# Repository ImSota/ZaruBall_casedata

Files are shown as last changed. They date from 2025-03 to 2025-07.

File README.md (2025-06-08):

# ZaruBall用3Dプリントデータ
ZaruBallとMackのケース、トラックボールケース、ロータリーエンコーダー用ノブのstlファイルを公開しています。<br>
mainブランチのデータはZaruBall v3以降のケースデータです。
v3より前のケースデータはversion1ブランチに保管してあります。

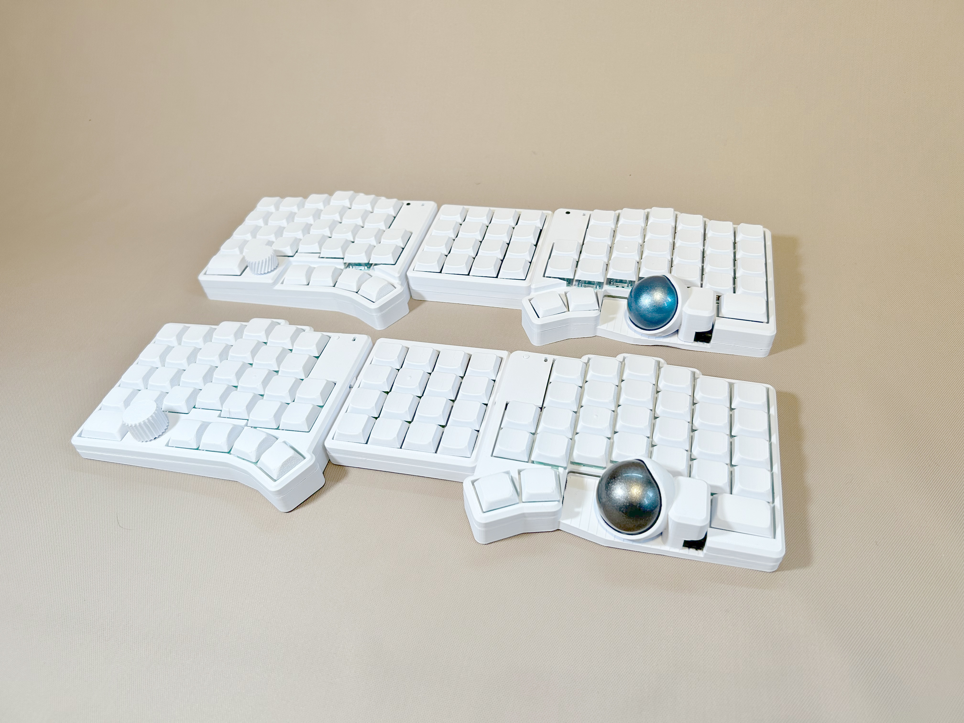
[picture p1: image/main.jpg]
main image


## ケースデータ
データ画保管先は[こちら](/case)<br>

ボトムケースはMack対応版とMack非対応版の2種類があります。
トップケースはロープロファイル版とMX版の2種類があります。
ファイル名の末尾で判別してください。
| 末尾の文字列 | 種類 |
| ---- | ---- |
| Mack | Mack対応版 |
| noMack | Mack非対応版 |
| LP | ロープロファイル版 |
| NP | MX版 |
<br>

3Dプリントパーツの他にも用意するパーツがあります。
| 用意するパーツ | 点数 | 寸法 |
| ---- | ---- | ---- |
| ネオジム磁石(ケース固定用) | ZaruBall:32個 Mack:8個 トラックボールケース:3個 | 直径2mm, 高さ2mmの円筒形 |
| ネオジム磁石(ZaruBall-Mack接続用) | 8個 | 直径6mm, 高さ2.5mmの円筒形 |
| セラミックボール | 3個 |  直径2mm |
| ゴム足 | ZaruBall:8個 Mack:4個 | 直径10mm |

## 組み立て方法

右手側のケース組み立て手順をご説明します。左手側、Mackもほぼ同様の手順で組み立てられます。
1. ケース固定用マグネットをトップケース、ボトムケース、トラックボールケースに圧入します。マグネットが入らない場合は2mmのドリルやマイナスドライバで穴を拡張します。緩く、マグネットが抜けてしまう場合は接着剤を穴に少量入れて固定してください。<br>
ボトムケースのトラックボール固定用マグネットは25mmボールと35mmボールで配置が異なります。トラックボールケースをボトムケースに当てはめてみて適切なマグネットの位置を探してください。
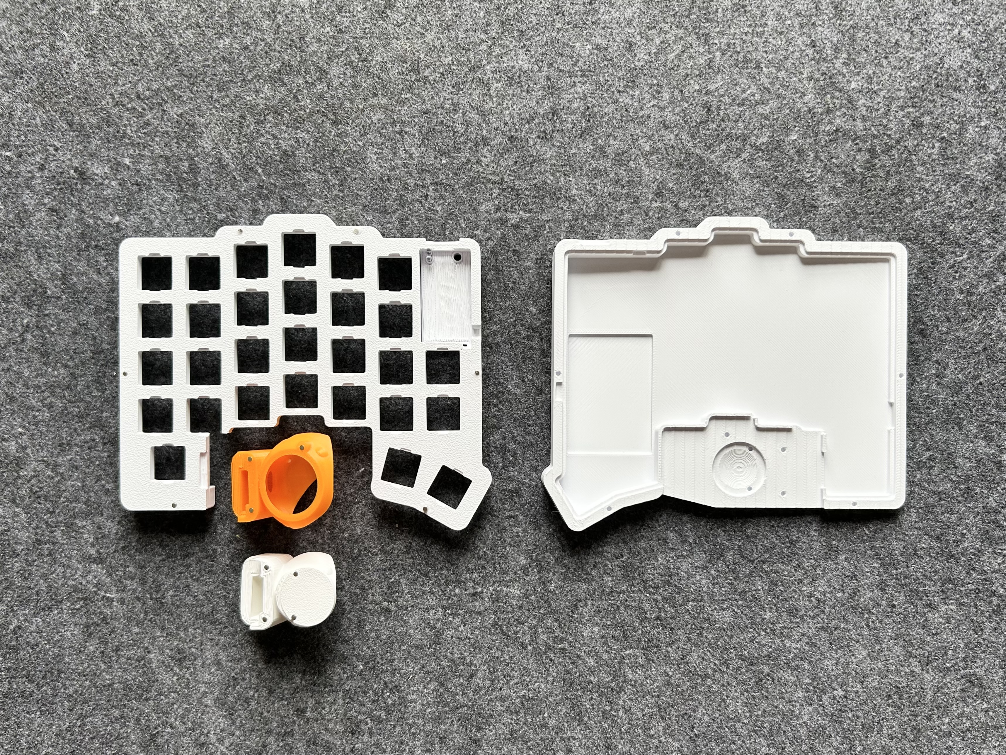
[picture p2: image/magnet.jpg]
insert magnet
    
2. セラミックボール3つをトラックボールケースに圧入します。固いものを押し当てることで簡単に圧入することができます。
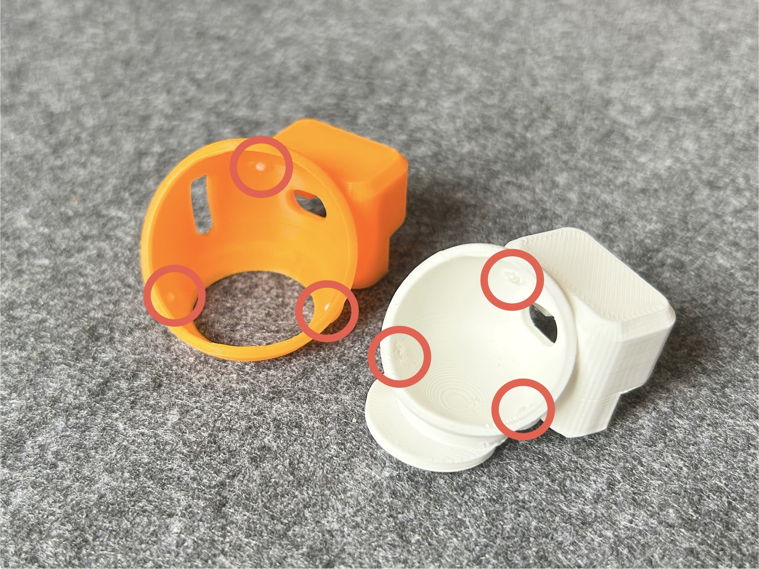
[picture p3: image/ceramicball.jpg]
insert_ceramic ball
    
3. トップケースにリセットスイッチと電源スイッチカバーを配置します。
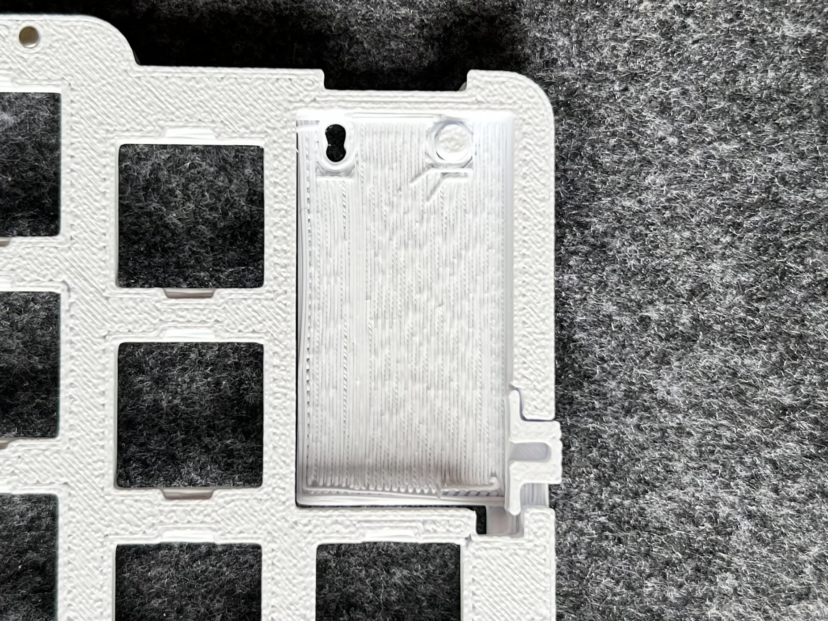
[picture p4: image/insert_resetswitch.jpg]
insert reset switch and power switch cover
    
4. PCBをトップケースにはめ込む。この時USB端子と電源スイッチを先にケースに入れるようにします。また、リセットスイッチが抜けないよう逆さにしたまま作業します。
    insert PCB
5. 四隅にスイッチをはめて、PCBとトップケースを固定します
    insert switches
6. ゴム足をボトムケースに貼付します。ゴム足固定用のくぼみがあるのでそこに合わせて貼り付けてください。
    putting rubberfeet
7. ボトムケースにMack接続用のΦ6mmマグネットを接着します。接続先のマグネットと吸着する向きにしてください。
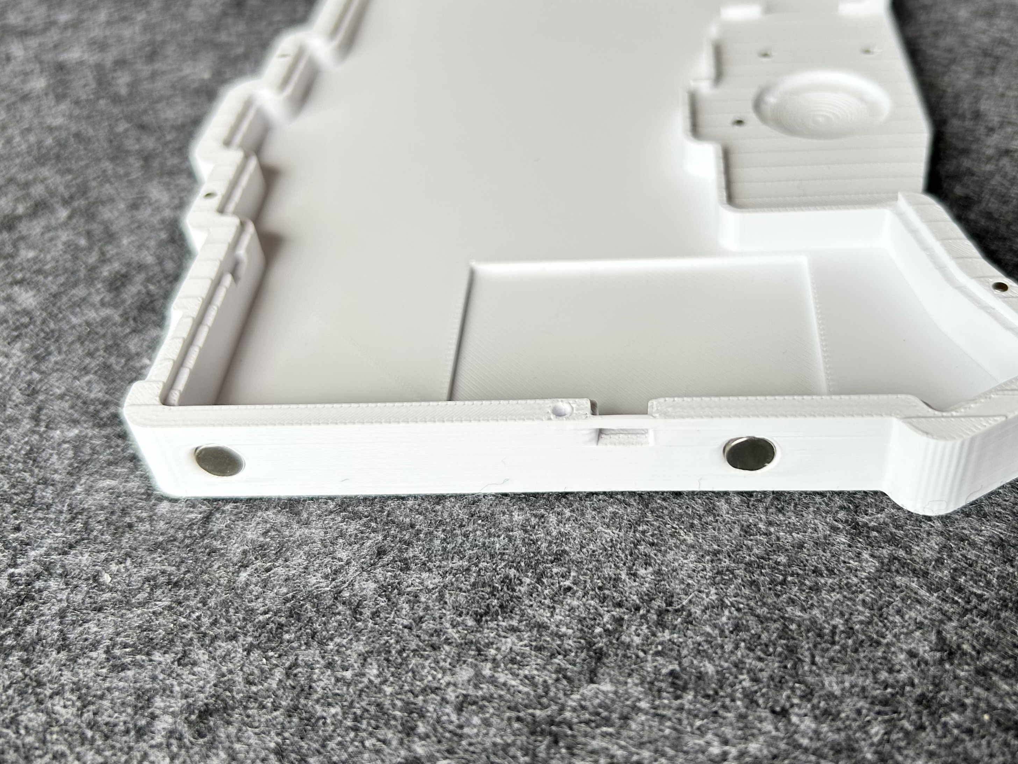
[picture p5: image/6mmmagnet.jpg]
6mm magnet
    
7. バッテリをボトムケースにマスキングテープ等で固定します。くぼみがあるのでそこにバッテリーを配置してください。
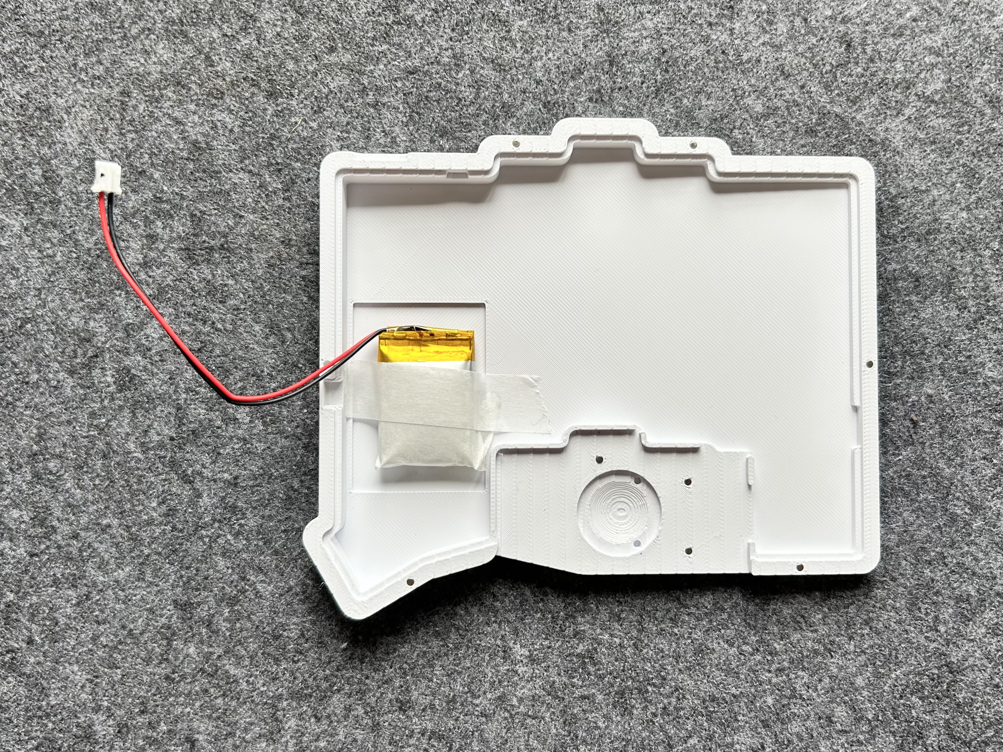
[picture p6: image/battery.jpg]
pinning battery
    
8. バッテリコネクタを接続し、ボトムケースとトップケースをマグネットで固定します。
9. すべてのスイッチとキーキャップ、トラックボール、ノブを取り付けます。
10. トラックボール基板のマグネットコネクタをPCBと接続し、トラックボール基板の上からトラックボールケースを被せます。
    trackball connect
11. マイコンのインジケータLEDの確認穴に2mmのアクリル丸棒を差し込むことで光が拡散し見やすくなります。
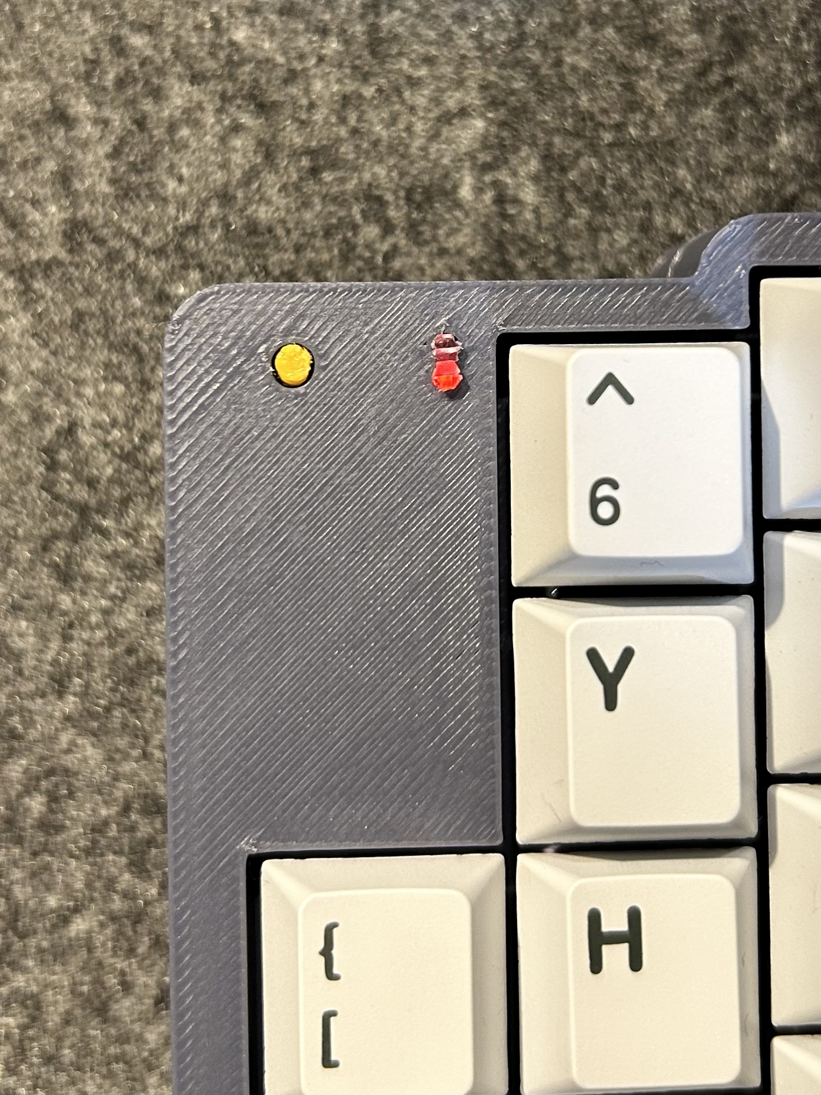
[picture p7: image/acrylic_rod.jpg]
insert acrylic rod


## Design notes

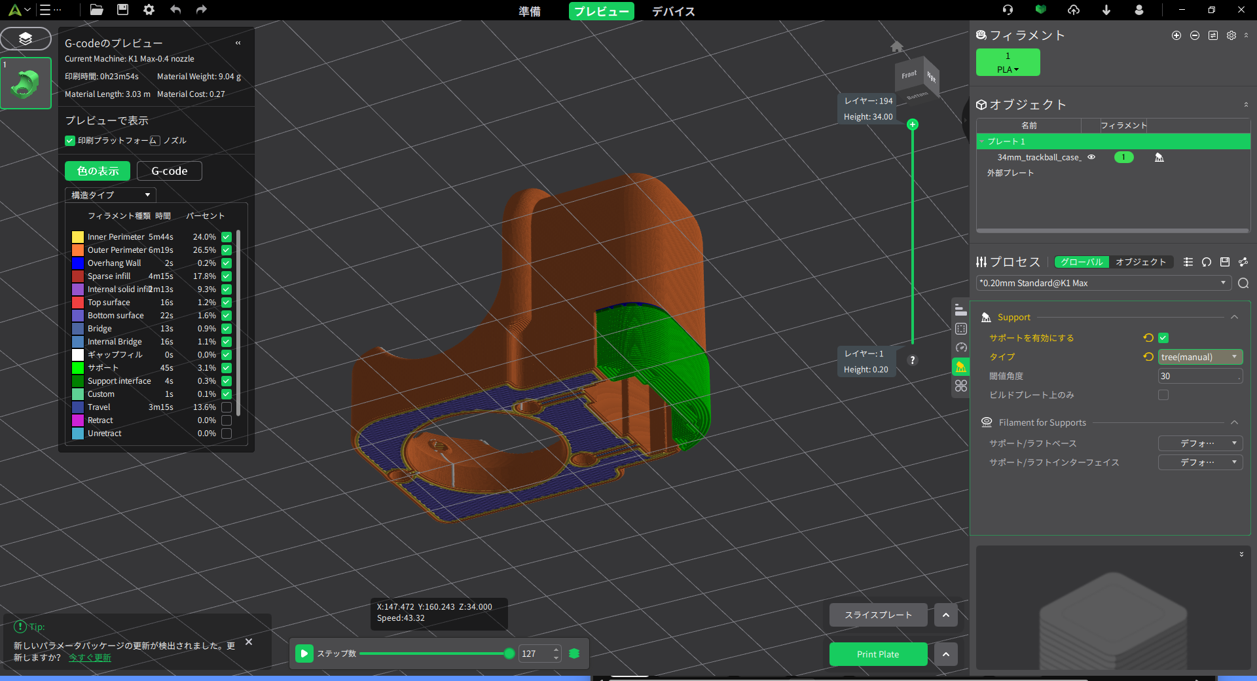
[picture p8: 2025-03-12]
image/image.png

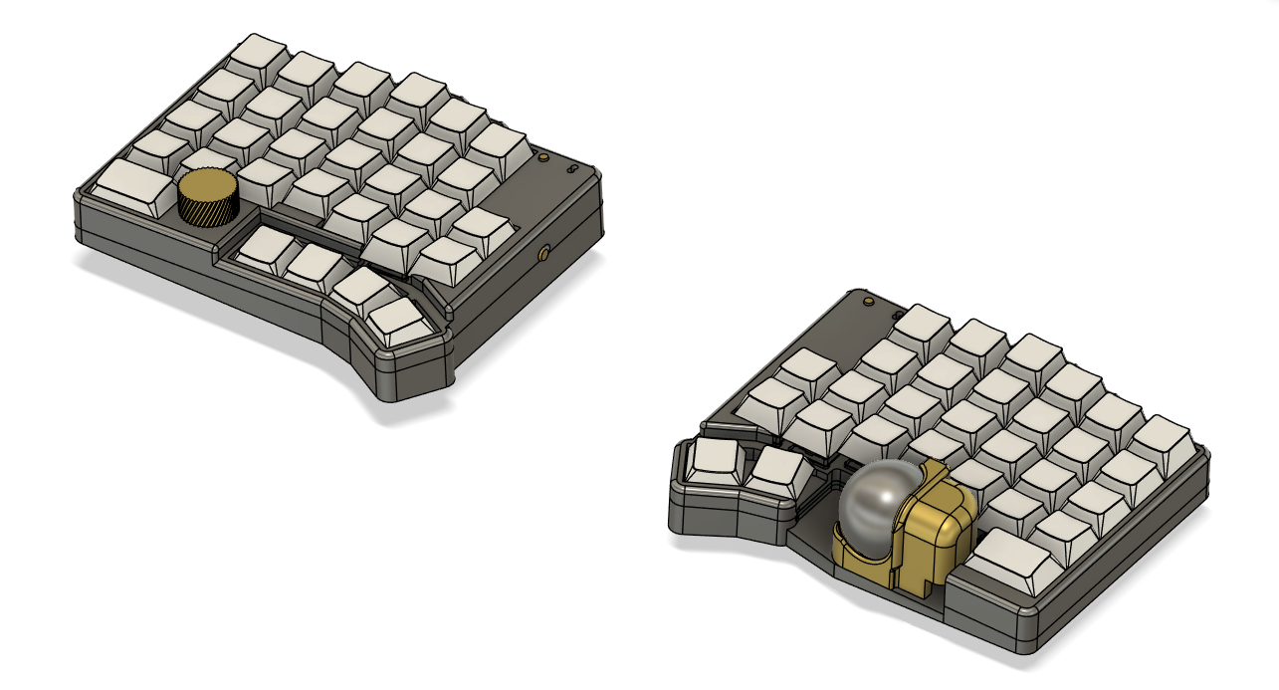
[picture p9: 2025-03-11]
image/2Pcase.png

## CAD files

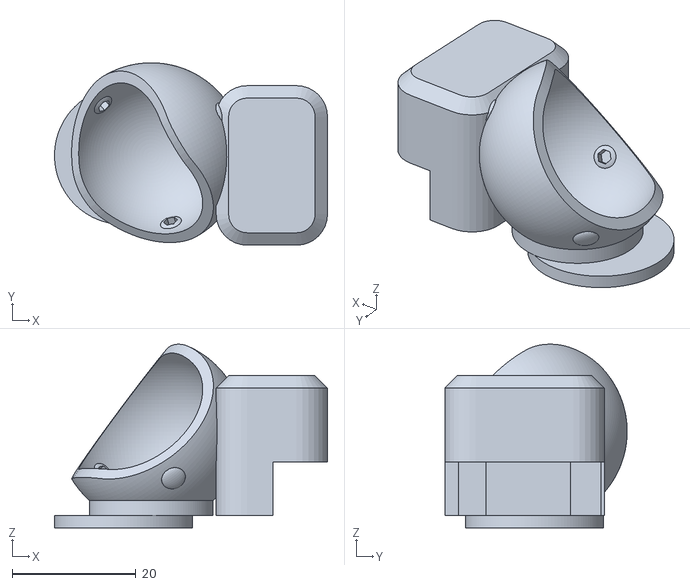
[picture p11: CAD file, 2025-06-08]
case/25mm_trackball.stl
44.1 x 29.5 x 29.7

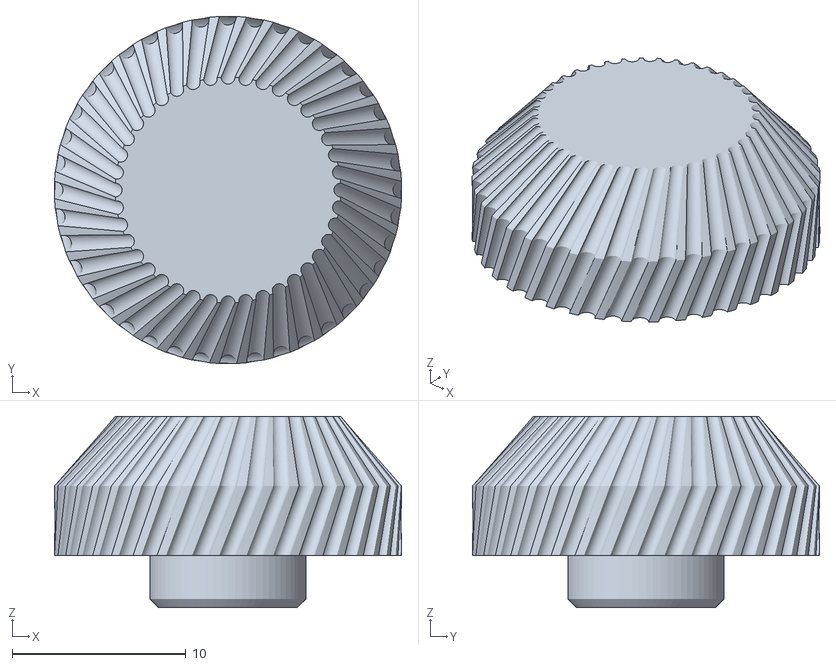
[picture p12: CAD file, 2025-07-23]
case/Knob/knob_LP.stl
20.0 x 20.0 x 11.0

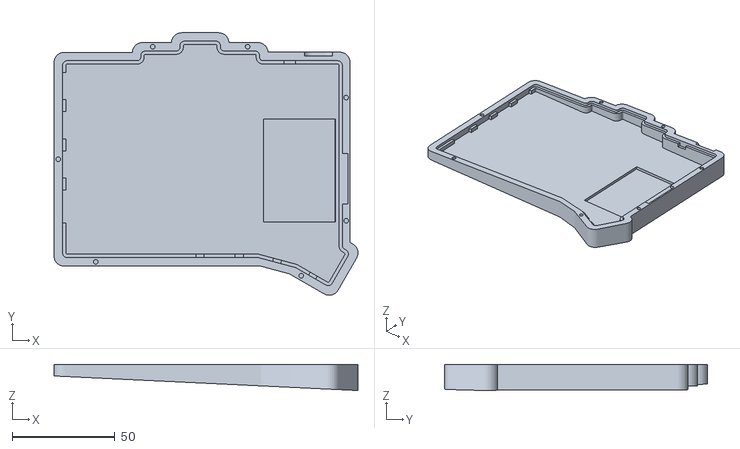
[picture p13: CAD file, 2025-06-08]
case/Left/bottom_noMack.stl
148.0 x 127.8 x 12.7

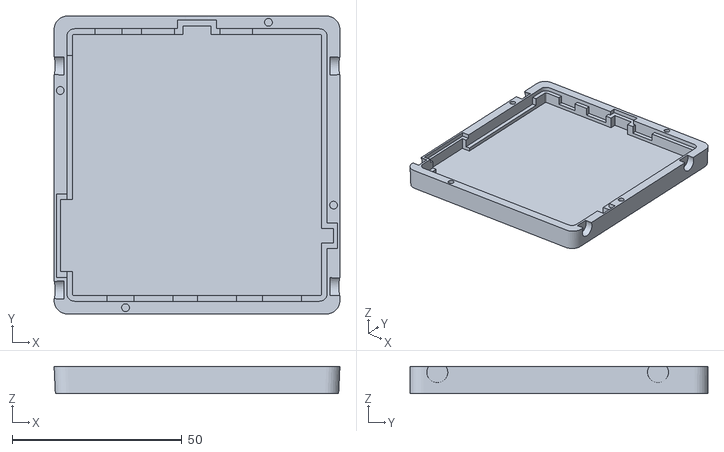
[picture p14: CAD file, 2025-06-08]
case/Mack/bottom.stl
84.2 x 87.8 x 8.00

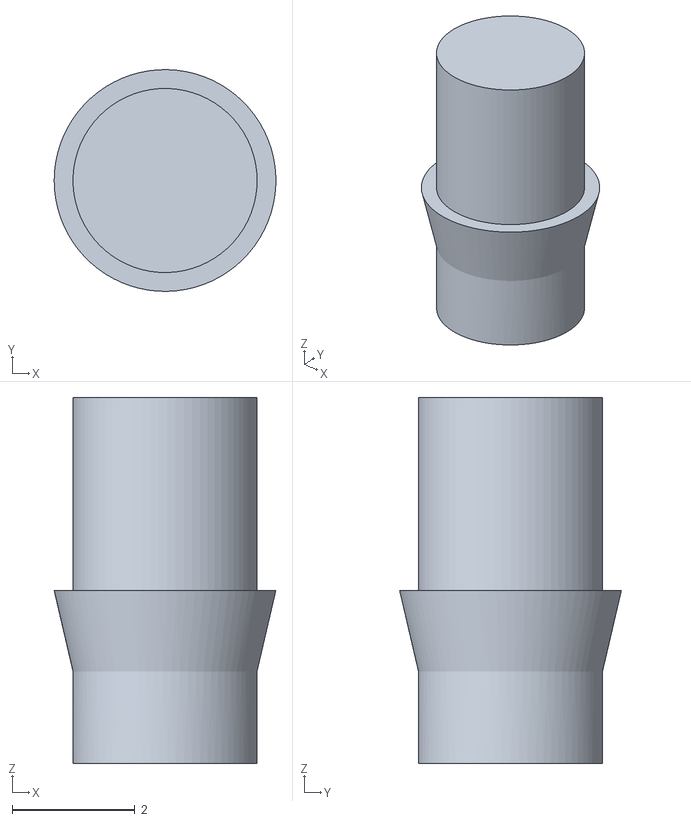
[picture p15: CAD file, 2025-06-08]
case/Reset_switch/reset_LP.stl
3.61 x 3.61 x 5.96

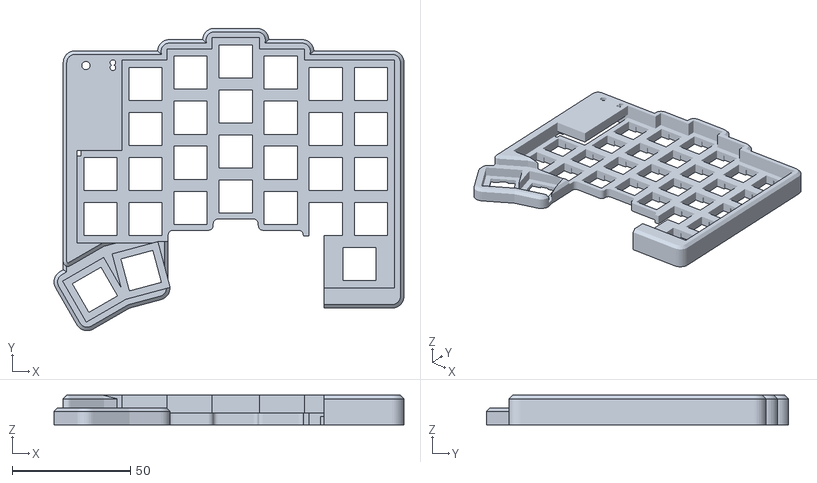
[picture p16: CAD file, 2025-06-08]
case/Right/top_NP.stl
148.0 x 127.9 x 12.5

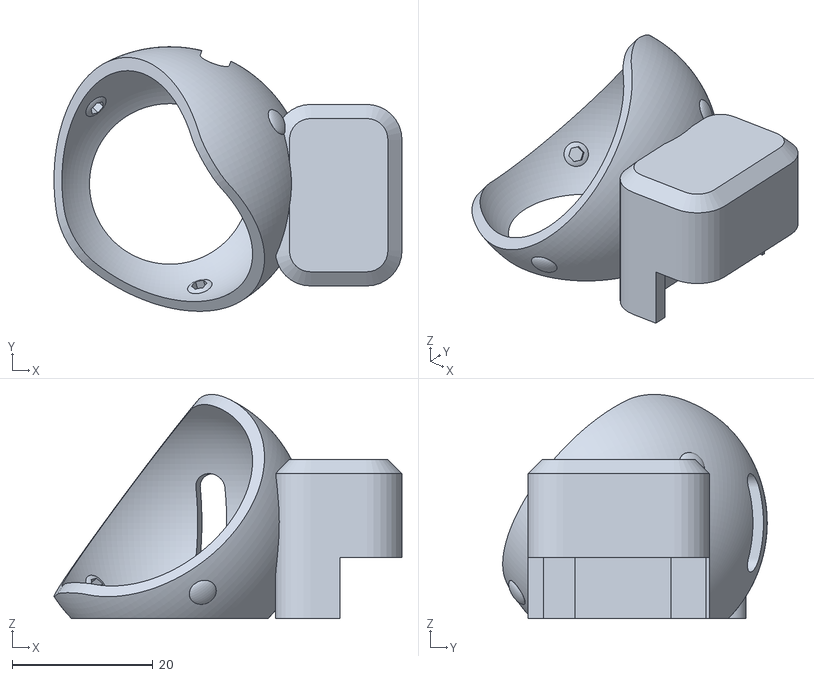
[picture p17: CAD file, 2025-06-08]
case/35mm_trackball.stl
49.5 x 37.6 x 31.9

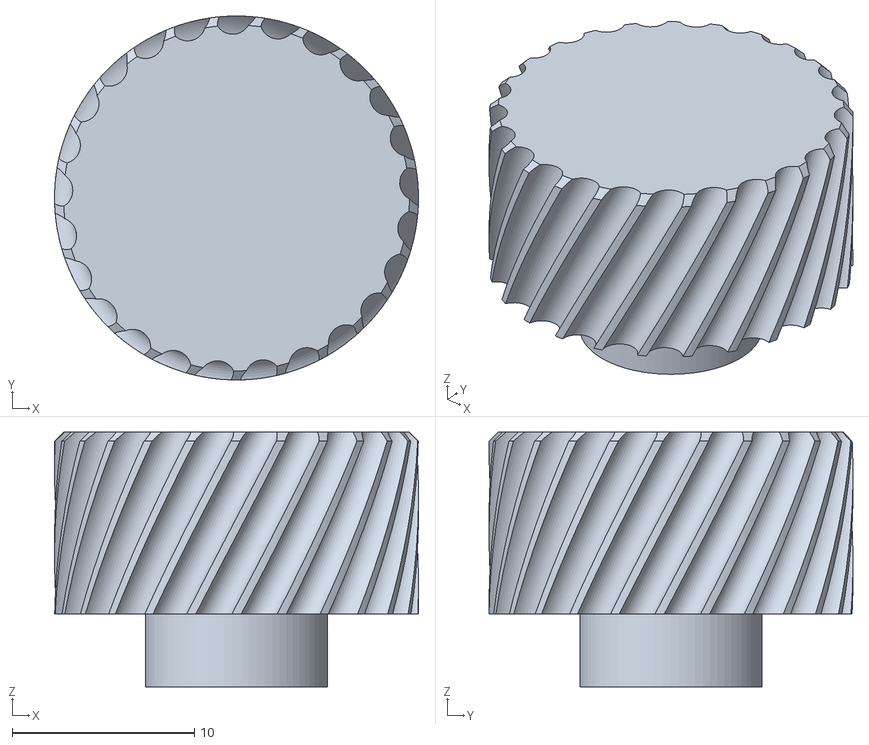
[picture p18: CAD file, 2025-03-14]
case/Knob/knob_NP.stl
20.0 x 20.0 x 14.0

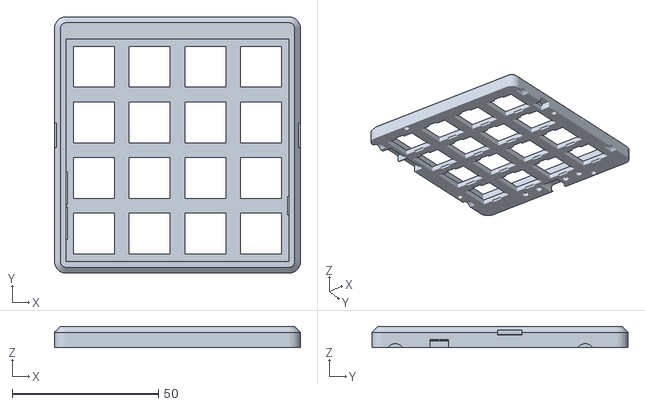
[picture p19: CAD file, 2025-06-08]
case/Mack/top_LP.stl
84.2 x 87.8 x 7.25

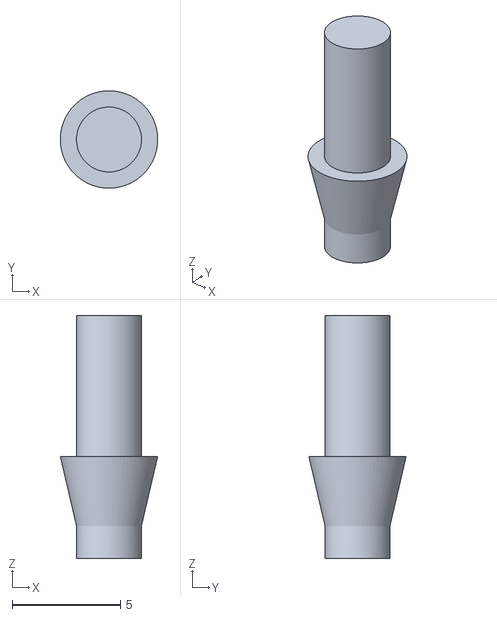
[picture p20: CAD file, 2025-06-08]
case/Reset_switch/reset_NP.stl
4.50 x 4.50 x 11.2

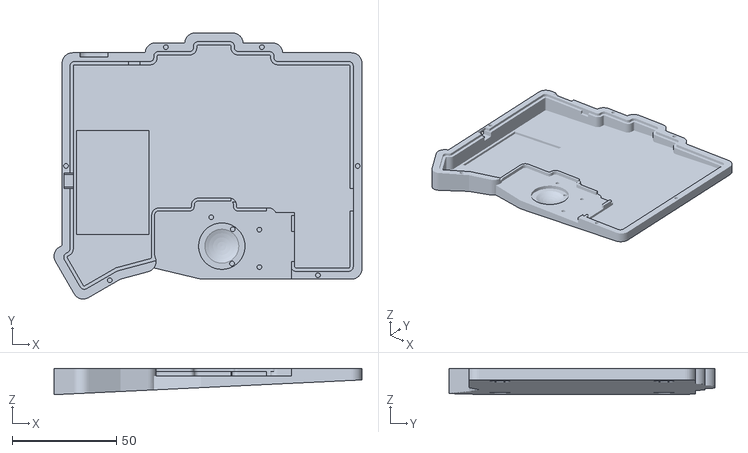
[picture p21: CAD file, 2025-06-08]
case/Right/bottom_Mack.stl
148.0 x 127.9 x 12.7

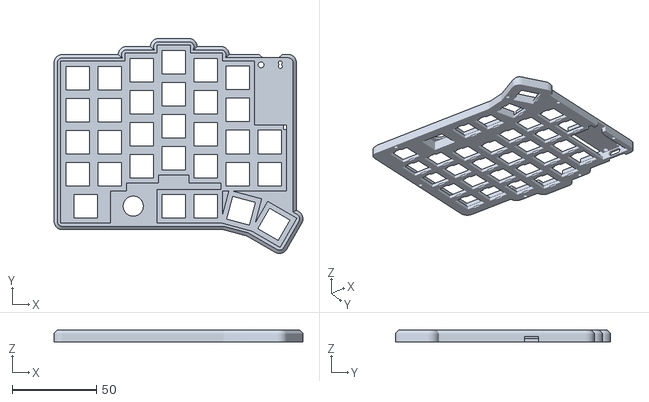
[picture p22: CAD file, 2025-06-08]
case/Left/top_LP.stl
148.0 x 127.8 x 7.20

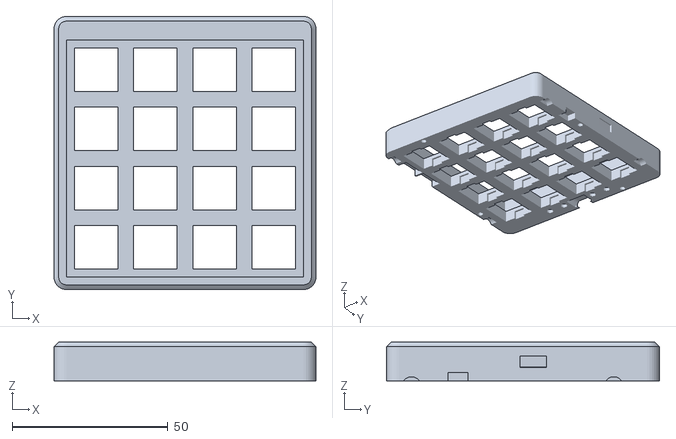
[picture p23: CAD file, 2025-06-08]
case/Mack/top_NP.stl
84.2 x 87.8 x 12.5

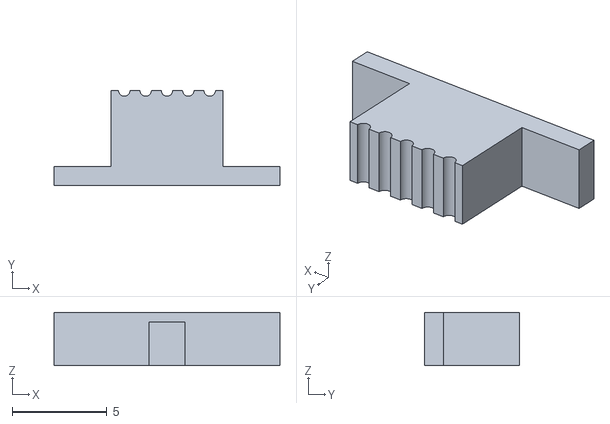
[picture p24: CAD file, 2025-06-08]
case/power_switch.stl
11.9 x 5.00 x 2.80

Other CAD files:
case/Left/bottom_Mack.stl
case/Right/bottom_noMack.stl
case/Left/top_NP.stl
case/Right/top_LP.stl

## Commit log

2025-03-06 print data and README
    [35mm_trachball_case.obj, left_bottomplate.obj, left_topplate.obj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]
2025-03-07 add choc v2 compatible plate data
    [left_bottom_plate.obj, left_bottomplate.obj, left_choc_plate.obj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]
2025-03-11 add 2P case stl data
    [34mm_trackball_case_for2P.stl, L_bottom.stl, L_top.stl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]
2025-03-11 add readme for 2Pcase
    [reset_switch.stl, reset_switch_cover.stl]
2025-03-12 fix readme
    [L_top.stl]
2025-03-14 update 2P case data
    [34mm_trackball_case_forsandwichcase.obj, L_bottom.stl, R_bottom.stl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]
2025-03-15 add 25mm trackball case
    [25mm_trrackball_case.stl]
2025-03-21 change Rbottom data
    [R_bottom.stl]
2025-06-08 version 1
    [34mm_trackball_case.stl, R_bottom.stl, R_top.stl]
2025-06-08 add v2 data
    [25mm_trrackball_case.stl, 34mm_trackball_case.stl, 34mm_trackball_case_forsandwichcase.obj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]
2025-06-08 add link to version1 case data
2025-06-08 add 3D data for Mack
    [bottom.stl, top_LP.stl, top_NP.stl]
2025-06-08 add 3D data for trackball case
    [25mm_trackball.stl, 35mm_trackball.stl]
2025-07-23 swap knob_LP.stl to newest data
    old knob_LP data was for normal EC11 rotary encoder
    Change it for low profile EC11
    [knob_LP.stl]
